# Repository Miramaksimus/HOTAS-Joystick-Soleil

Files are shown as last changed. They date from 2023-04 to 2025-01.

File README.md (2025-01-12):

# 3D-printed HOTAS Joystick Soleil: F-16 Sticks + housing + twist rudder controls

## Features:
- Removable stick
- Two different stick's size, improved stick's parts mounting, used other type of 5-way Hat/POV Switches
- Improved Gimbal parts mounting, corrected the dimensions of the holes for the bearings
- Two different types of housing, one with additional axes and toggles

## 3D Model
You can see the assembled 3D models in web:
- [Short Size Stick](https://a360.co/3PqR6vJ)

- [Normal Size Stick](https://a360.co/3PvqF8i)

- [Cylindrical JoyStick Base](https://a360.co/3Li3Hh7)

- [Rectangular JoyStick Base](https://a360.co/3q2hyS1)

## Printing
- White and black PLA+, red PET-G
- Rafts: Yes
- Supports: Yes
- Infill: 20 - 30 - 60%
 
## Components (not complete)
- Bearing 6802zz (15x24x5mm) - 5 units
- Bearing MF105zz - 8 units
- Bearing 685zz - 4 units
- Adhesive non-slip pad 200x200mm - 1 init
- The TLE5011/5010 sensors - 2 units
- Hall-effect sensor (SS49E for example) - 1 unit
- Ceramic capacitor 50V 104 100nF 0.1uf - 1 unit
- Cylindrical magnets (5x10mm) - 4 units
- 5-Way Switch 10x10x10mm Multi Direction Switch Touch Reset Button - 4 units
- Push Button 6x6 4.3mm - 5 units
- Miniature toggle switch (on/of/on or reset/of/reset ) - 2 units
- Potentiometer (WH148) 10K Ohm (B10K) - 3 units
- Switching Diode (for example 1N4148) - 30 units
- Micro-USB 5pin Micro USB 2.0 Male to USB 2.0 B Type Female Connector Cable 30cm With Panel Mount Hole cables - 1 unit
- Wires - 28-32 AWG 
- Hot Glue - 1 unit
- Two Component Epoxy Glue or Super Glue- 1 unit
- Low-cost STM32F103C8 microcontroller - 1 unit
- [FreeJoy soft and manual](https://github.com/FreeJoy-Team/FreeJoyWiki)

### Screws, nuts, etc…
- WiP - [See the answer to the issue](https://github.com/Miramaksimus/HOTAS-Joystick-Soleil/issues/3#issuecomment-2561463725)

##  Images
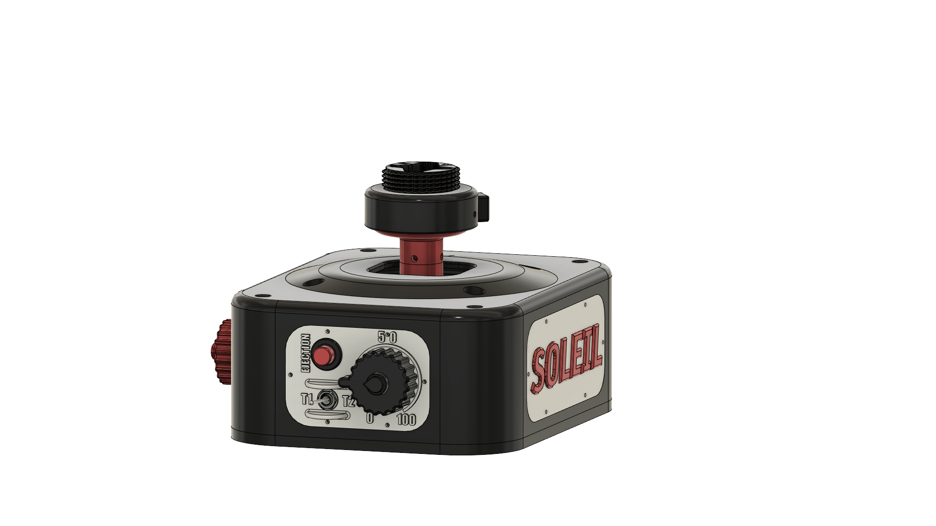
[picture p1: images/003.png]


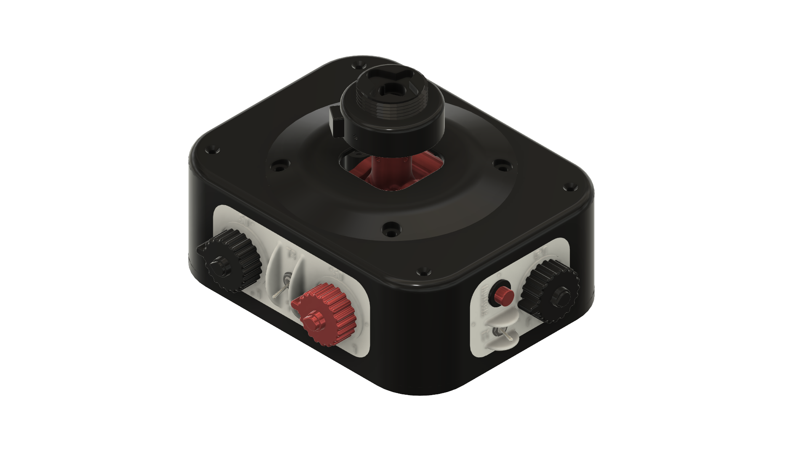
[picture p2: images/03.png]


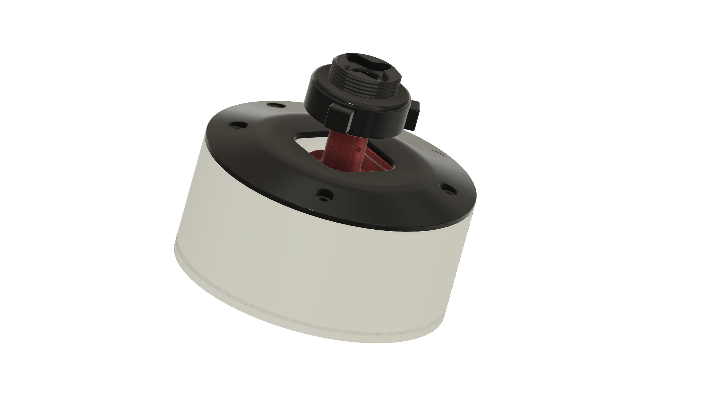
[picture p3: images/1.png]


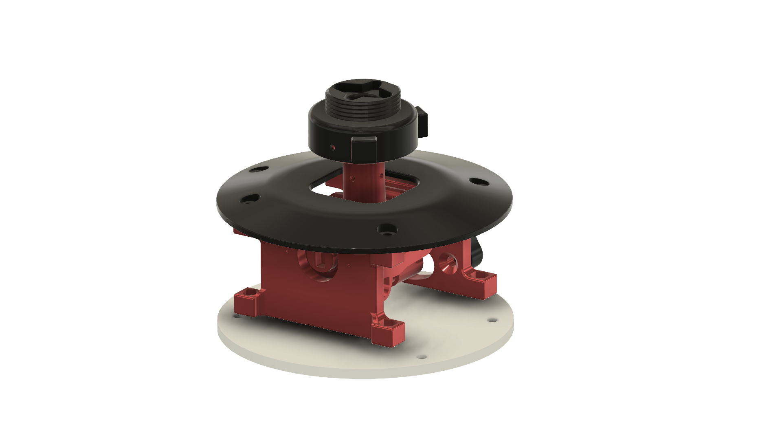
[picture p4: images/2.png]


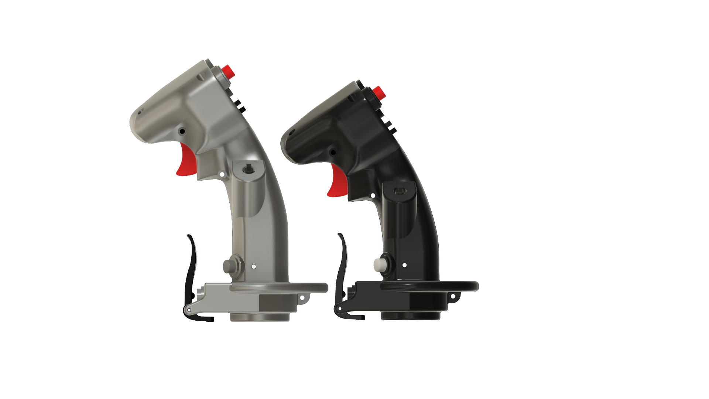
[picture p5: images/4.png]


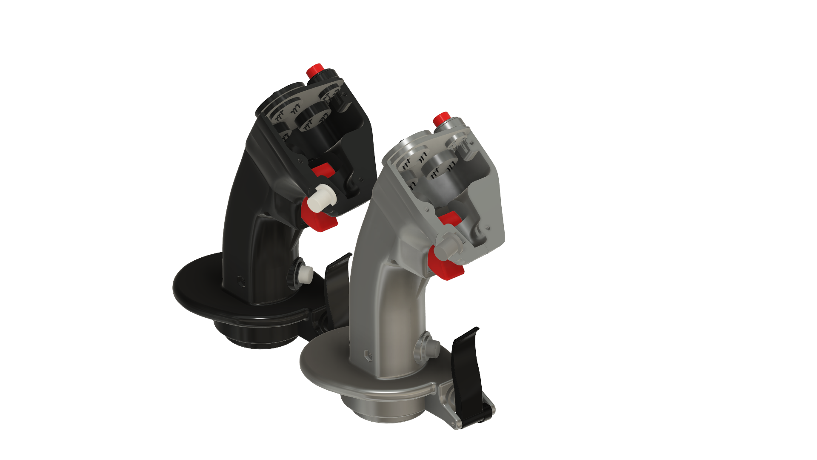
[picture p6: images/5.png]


##  Video

3D-printed HOTAS Joystick Soleil: F-16 Sticks + housings + twist rudder controls (https://www.youtube.com/watch?v=IS1_Lb0nVMM)

## **If you find this design helpful, consider  to support my work and my future projects. Thanks in advance.**

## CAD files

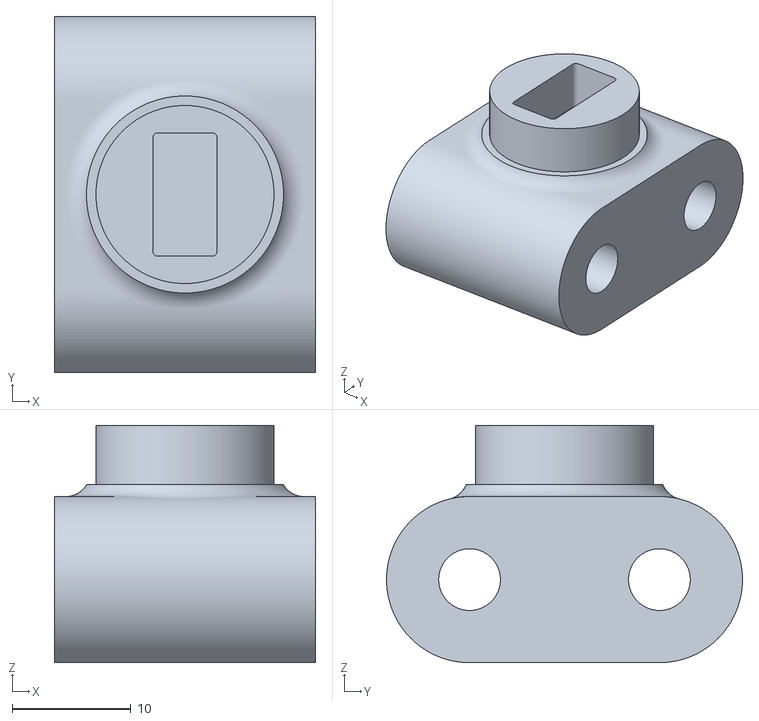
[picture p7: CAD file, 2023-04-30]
export/gimbal/stl/gimbal_core_pot_side.stl
22.0 x 30.0 x 20.0

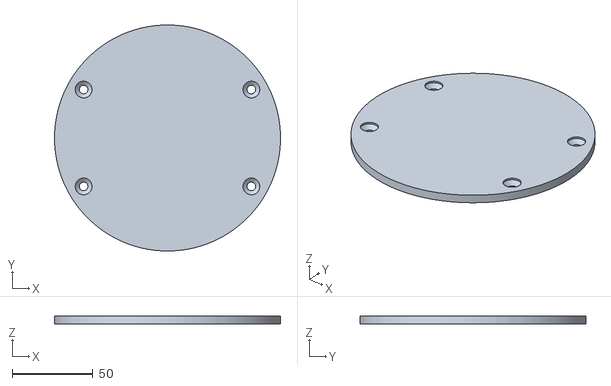
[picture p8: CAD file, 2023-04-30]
export/housing/cylindrical/stl/housing_base.stl
140.0 x 140.0 x 5.00

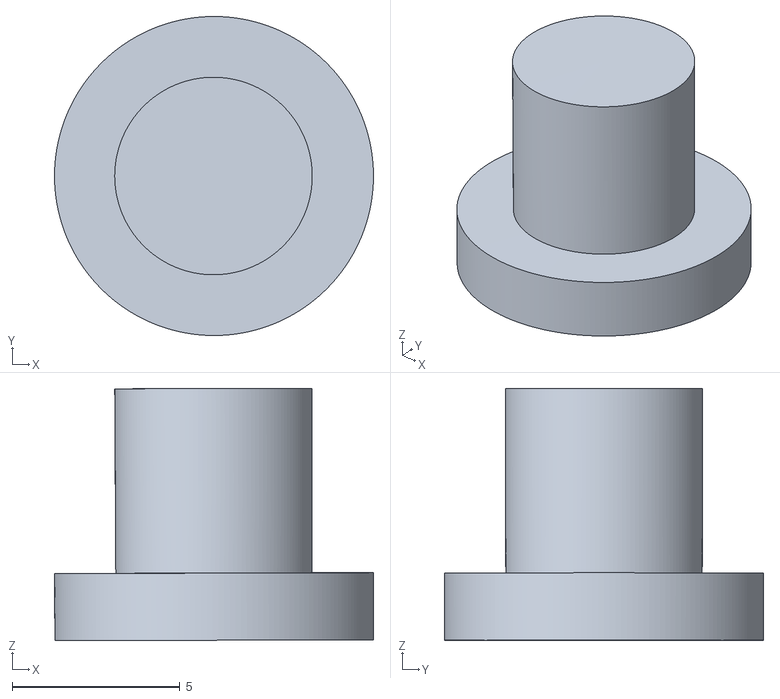
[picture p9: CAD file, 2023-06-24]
export/housing/rectangular/stl/button_rod.stl
9.51 x 9.51 x 7.53

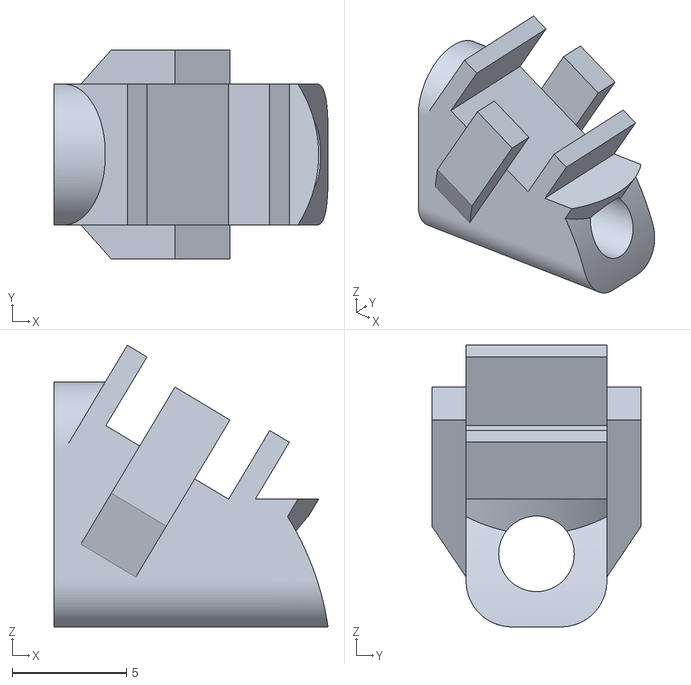
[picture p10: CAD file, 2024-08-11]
export/stick/common_parts/stl/pinkie_holder.stl
12.0 x 9.15 x 12.3

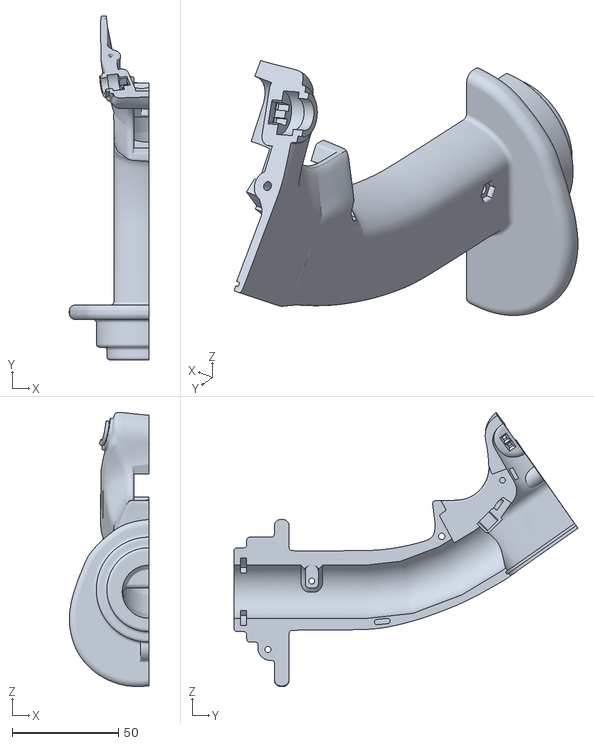
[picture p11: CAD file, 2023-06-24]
export/stick/normal/stl/Right.stl
37.4 x 162.0 x 129.1

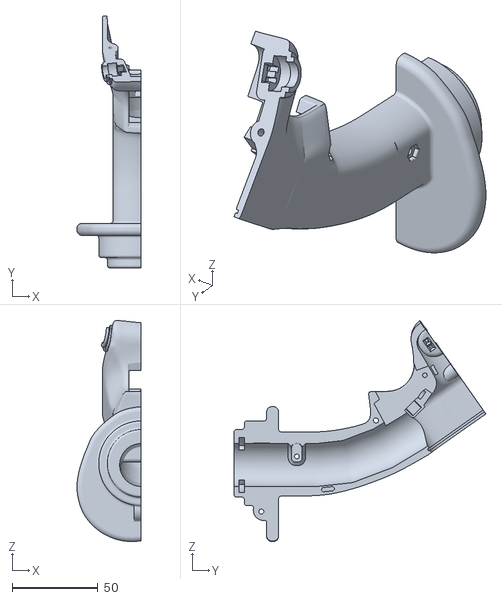
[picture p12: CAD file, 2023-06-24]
export/stick/short/stl/Short-right.stl
37.4 x 147.0 x 129.0

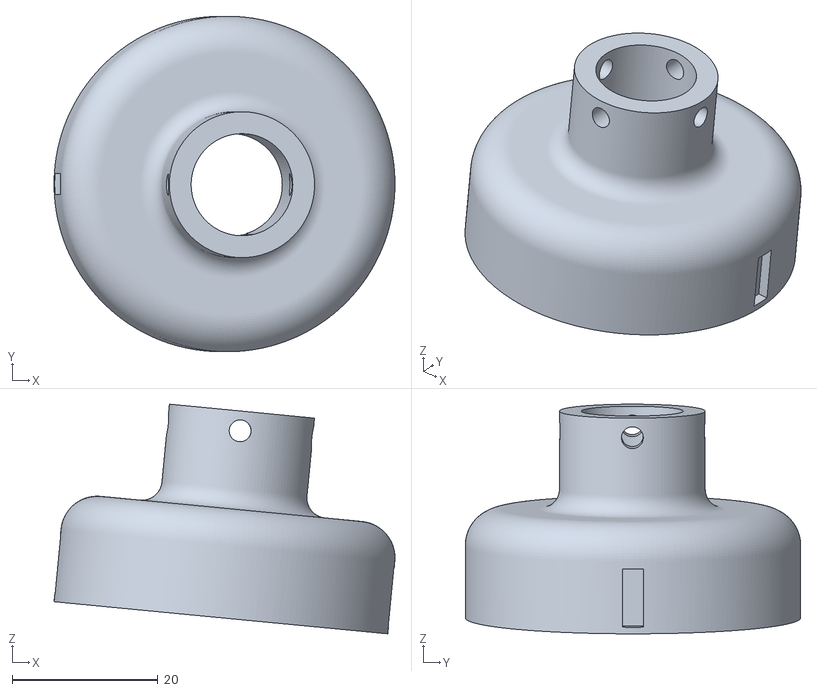
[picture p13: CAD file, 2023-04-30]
export/twist/stl/twist_rudder_controls_bottom_new.stl
46.8 x 46.0 x 31.5

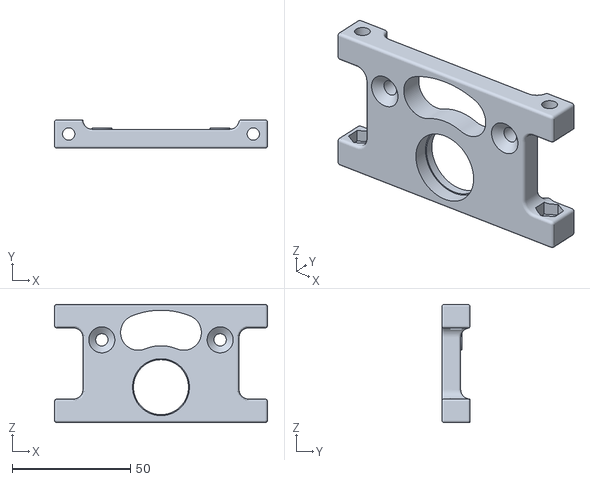
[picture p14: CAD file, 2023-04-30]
export/gimbal/stl/gimbal_frame_alt.stl
90.0 x 12.0 x 50.0

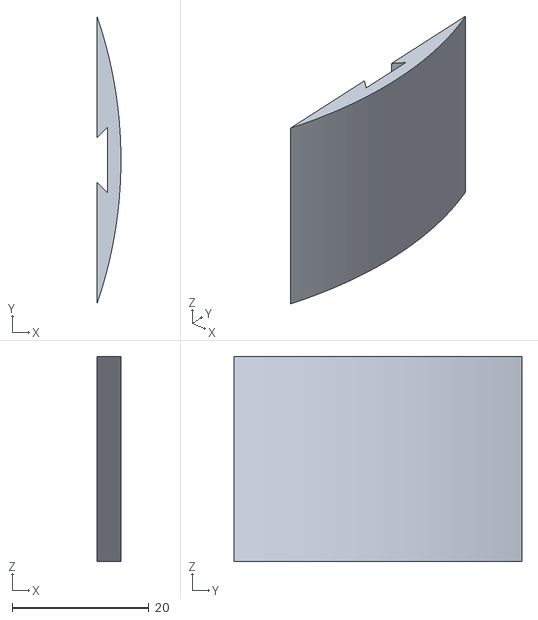
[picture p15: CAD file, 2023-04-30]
export/housing/cylindrical/stl/housing_bluepill_socket.stl
3.50 x 42.1 x 30.0

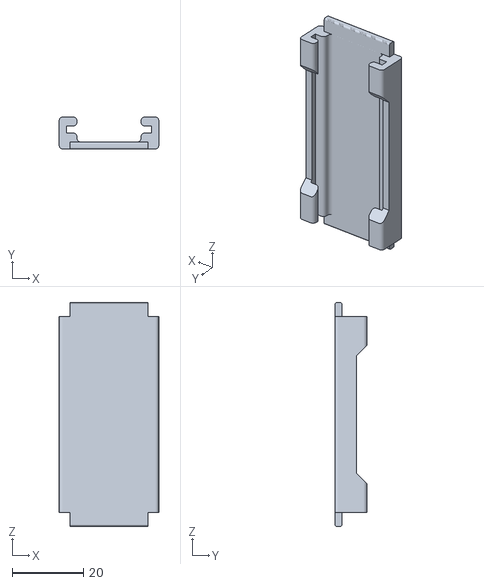
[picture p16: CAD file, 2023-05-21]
export/housing/rectangular/stl/bluepill-rect-frame.stl
28.0 x 9.00 x 63.0

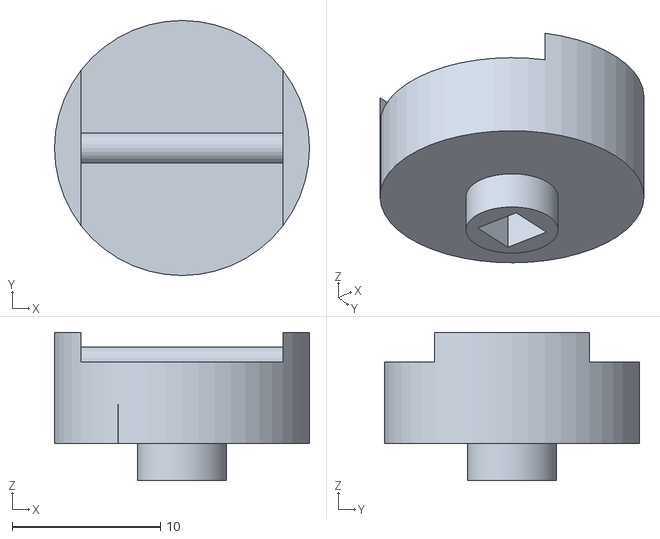
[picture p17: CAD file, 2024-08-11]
export/stick/common_parts/stl/cms_hat.stl
17.2 x 17.2 x 10.00

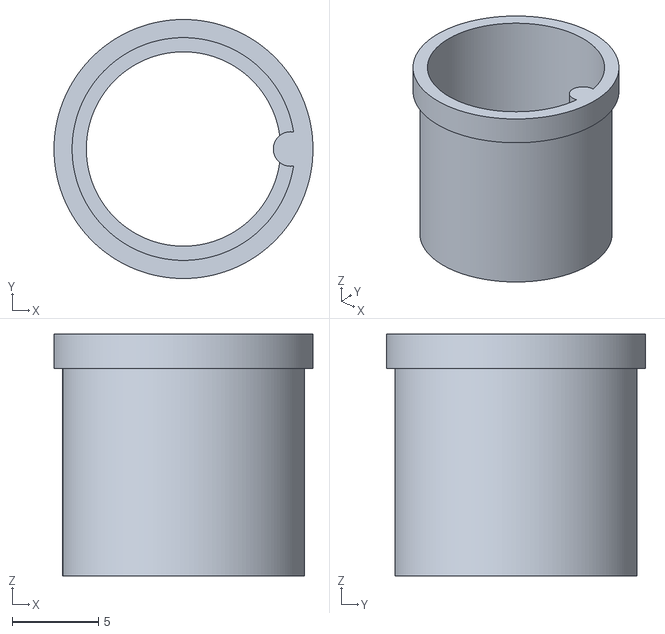
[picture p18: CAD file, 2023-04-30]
export/twist/stl/twist_adapder_top_bushing.stl
15.0 x 15.0 x 14.0

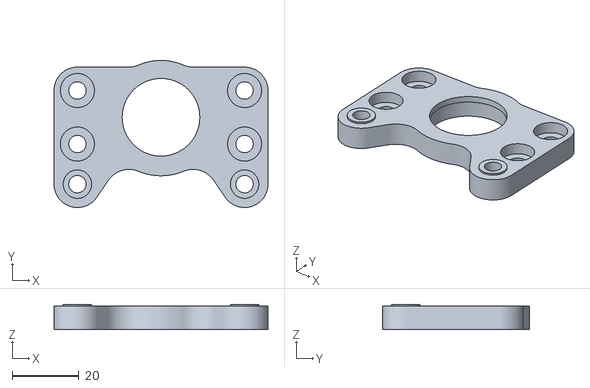
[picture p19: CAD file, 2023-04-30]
export/gimbal/stl/gimbal_core_bearing_carrier.stl
64.0 x 44.0 x 7.50

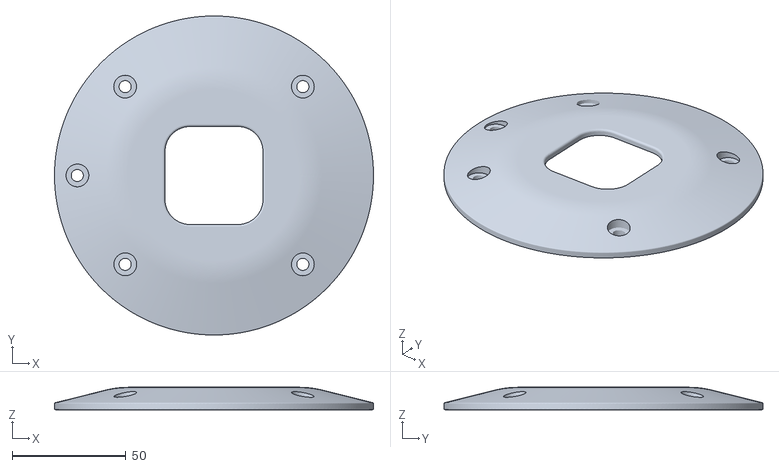
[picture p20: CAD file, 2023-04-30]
export/housing/cylindrical/stl/housing_cover.stl
140.0 x 140.0 x 9.88

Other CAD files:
export/housing/rectangular/stl/box_frame.stl
export/stick/common_parts/stl/dms_hat.stl
export/twist/stl/gimbal_lever_arm.stl
export/gimbal/stl/gimbal_core_bearing_carrier_alt.stl
export/gimbal/stl/gimbal_cam.stl
export/gimbal/stl/gimbal_core_non_pot_side.stl
export/gimbal/stl/gimbal_frame.stl
export/gimbal/stl/gimbal_lever_arm.stl
export/housing/cylindrical/stl/housing_bluepill-1.6mm.stl
export/housing/cylindrical/stl/housing_body.stl
export/housing/rectangular/stl/box_bottom.stl
export/housing/rectangular/stl/box_cover.stl
export/housing/rectangular/stl/button_red_cap.stl
export/housing/rectangular/stl/front_cover.stl
export/housing/rectangular/stl/left_cover.stl
export/housing/rectangular/stl/potentiometr_knob.stl
export/housing/rectangular/stl/right_cover.stl
export/housing/rectangular/stl/soleil.stl
export/stick/common_parts/stl/Face.stl
export/stick/common_parts/stl/Face_alter.stl
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

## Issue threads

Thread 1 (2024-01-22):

Questions about sensor and installation

LUCKandII, 2024-01-22:
Great job and thanks for your sharing!I have some question about the sensor and would you mind give me some answers?
* You mentioned 2 unit TLE5011/5010 sensors and 1 unit Hall-effect sensor in your project, I wonder which of these is for z axis?
* How to inatall z axis magnet?I don't see room to mount magnets and sensors. Can you share some pictures of the installation?
* TLE5011/5012 sensor use SPI bus for communication.Dose freejoy support 2 or more SPI device? In the configure page, it seems there's no distinction two different spi devices... Would you mind to share some key config (files/picture/anything else) about this?
* How do these two pieces fit together?If I use screws, it seems that it can't be twisted.

Thank you in advance for your help!

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

Miramaksimus, 2024-01-22:
Here are the fixed answers:

1. The TLE5011/5010 sensors are utilized for the X and Y axes, as demonstrated in the video (https://youtu.be/IS1_Lb0nVMM?t=363). For the Z-axis, a Hall-effect sensor is employed (image1) -use hot glue to secure the sensor position.
2. For guidance on installing the Z-axis magnets, refer to the available images demonstrating the installation process (image2 and image3).
3. For configuring the TLE5011/5010 sensors (not the TLE5012), please find my configuration details in image4.
4. If you wish to disable the twisting functionality, screws are provided for this purpose. However, if you want to enable twisting, it is recommended to use super glue for assembly. Secure the twist's bottom part with super glue to the bearing, assemble the twist, check for proper functionality, and then attach the top twist part with super glue to the inside of the bearing. This method ensures a secure assembly while allowing the necessary twisting motion. (See how to install the bearing: https://youtu.be/IS1_Lb0nVMM?t=381)

For more in-depth information and insights from the community, it is advised to check the description, comments, and responses on the Thingiverse page (https://www.thingiverse.com/thing:5976575). Exploring remixed versions and related content on Thingiverse can also provide valuable tips, modifications, and community feedback.

Additionally, you can find helpful visual guides and demonstrations related to joysticks on my YouTube channel (https://www.youtube.com/watch?v=4qccZbGVc9M&list=PL6WOn1wgybe4zLbwNDsI1c768gBqbFAPy&index=4).

image1

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

image2
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

image3
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

image4
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

LUCKandII, 2024-01-27:
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

Thank you! I've prepared all 3d printed components and "shopping list".  I think the best way to thank you is to recreate your work!

Closed 2024-01-23.

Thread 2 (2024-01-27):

Question about wiring hardware connection

LUCKandII, 2024-01-27:
Hi, I've watched your youtube video and your thingiverse page and really learned a lot! I also have some questions about wiring hardware connection:

* How to connect 4/5-way Switch to stm32 blue pill? Do you use 4/5-way Switch as keyboard array? Would you mind to share some more information about this?

* It makes me more curious about your wiring that you flight stick is replaceably with pogopin! It seems impossible to connect all the switch on the stick with only 10 pogopins (showed in the video) since it has FOUR 4/5-way switch and TWO push buttons because 4/5-way switch has at least 4 pin for each and push has at least 1 pin for each.Do you used resistance to make 4/5-way switcs as analog output? Would you mind to share more information about you pogopin design?

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

Miramaksimus, 2024-01-27:
Hi, there is one answer to your two questions - a matrix of buttons. You can find more details [here](https://github.com/FreeJoy-Team/FreeJoyWiki/blob/master/eng/Connecting-buttons-directly-to-controller.md).

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

With a 5x5 matrix, you can connect 25 buttons on the F-16 stick:

- three 5-way switches
- one 4-way switch
- 6 buttons

In the screenshot with the pin configuration from your previous issue, you can see a 5x6 matrix configured, which allows connecting 30 buttons (25 on the stick and 5 on the base of SOLEIL).

[The WiKi of the FreeJoy project](https://github.com/FreeJoy-Team/FreeJoyWiki/tree/master) could be useful for you.

LUCKandII, 2024-02-29:
Thanks for your help! I couldn't wait to share my joystick to you!
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

Miramaksimus, 2024-03-02:
You are welcome! It is amazing make! If you wont you can post your make in https://www.thingiverse.com/thing:5976575

I uploaded short video that can help you with trigger:

https://www.youtube.com/shorts/-YpK8iMiVb8

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

LUCKandII, 2024-03-10:
Thanks a lot! I fixed my trigger finally and made a [throttle-quadrant](https://github.com/Miramaksimus/throttle-quadrant-fokker-8-axes-and-31-buttons) these day! So excited to share with you!
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
I have a new question now... I connected stick and throttle to PC and running DCS, but one of my freejoy device setting is invalid. Did you use both stick and throttle in the same time and meet similar problem? I guess it might have something to do with the freejoy USB VID and PID https://github.com/FreeJoy-Team/FreeJoy/issues/209#issuecomment-1975108704.  I tried to modify USB VID and PID but this problem still unsolved. Do you have any ideas?

LUCKandII, 2024-03-10:
Well... Modifying USB VID and PID does work! All needed to do is restart DCS program!
I will post my making to thingivese later!

LUCKandII, 2024-03-23:
@Miramaksimus
Here is my make!
https://www.thingiverse.com/make:1165394
https://www.thingiverse.com/make:1165395

Miramaksimus, 2024-03-23:
Thank you!

Ahmet0691, 2024-11-12:
Can you share a photo of the direction of the diode facing the key? What is the name of the connectors you are using? And what is the task of bringing the joystick back to the center point, is it a spring or a rubber? [Is the diode looking at the chip or the button?]

LUCKandII, 2024-11-13:
> Can you share a photo of the direction of the diode facing the key? What is the name of the connectors you are using? And what is the task of bringing the joystick back to the center point, is it a spring or a rubber? [Is the diode looking at the chip or the button?]

* A photo of the direction of the diode facing the key. I made a key matrix PCB and all diodes are weilding on it. The diode is IN4148W, SOD-123 footprint.
* Any wire-to-wire connector is fine as long as it's easy to buy. I don't have an exact name of my connector... It's just some kind of 1.25mm 6P wire-to-wire connector.
* Joystick back to the center point using spring. [This video gives more information](https://www.youtube.com/watch?v=IS1_Lb0nVMM)
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

SirPotatoCat, 2024-12-21:
> Thanks for your help! I couldn't wait to share my joystick to you! It works perfect except the trigger botton.I will try to fix it. Your throttle quadrant is my next goal! ![1000012699](https://private-user-images.githubusercontent.com/44010936/308768615-df7ef069-b023-4bdc-b04c-dadd48d03fa9.jpg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) ![1000012700](https://private-user-images.githubusercontent.com/44010936/308768640-fe9db7c2-2d38-43e6-8a9b-feb0b18bd15a.jpg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) ![1000012701](https://private-user-images.githubusercontent.com/44010936/308768654-421a5d77-4dad-45a6-8af6-45d2ac85e38a.jpg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) ![1000012705](https://private-user-images.githubusercontent.com/44010936/308768666-02b718bc-bc69-4e15-8511-56ec3dc625d0.jpg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)

I'm looking forward to building this, I have all the parts ready to order but i was wondering if you knew which screws is should order? The originally model he remixed this from seemed to just screw right into the plastic but in his video he has nuts?

LUCKandII, 2024-12-22:
> I'm looking forward to building this, I have all the parts ready to order but i was wondering if you knew which screws is should order? The originally model he remixed this from seemed to just screw right into the plastic but in his video he has nuts?

Nuts are necessary. Mostly M3 and M4 nuts. It's a compoment list in readme of this project.

Miramaksimus, 2024-12-22:
> Can you share some information about joystick pogopin definition? Is it the same as warthgo HOTAS?

Yes, it is remixed from https://www.thingiverse.com/thing:3097965

Closed 2024-01-31.

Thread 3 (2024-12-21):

Screws

SirPotatoCat, 2024-12-21:
I'm looking forward to building this, I have all the parts ready to order but i was wondering if you knew which screws is should order? The originally model he remixed this from on thingverse seemed to just screw right into the plastic but in his video he has nuts?

Sciencesold, 2024-12-24:
Primarily its M5 hardware with a few M3 and M2, I have a variety pack of both with the M5 having various lengths between 8mm and 35mm. you do nee 2 Flat Head m5, but everything else can be Button Head. All the nuts are M5 obviously. You only need a handful of M3, primarily for the main top and bottom plates and the stick. I don't know the lengths off the top of my head, but one was a longer size I had to order a pack with m3x25 through m3x40 to find one that worked. M2 are for attaching the side plates.

Wizard-pope, 2025-01-11:
> Primarily its M5 hardware with a few M3 and M2, I have a variety pack of both with the M5 having various lengths between 8mm and 35mm. you do nee 2 Flat Head m5, but everything else can be Button Head. All the nuts are M5 obviously. You only need a handful of M3, primarily for the main top and bottom plates and the stick. I don't know the lengths off the top of my head, but one was a longer size I had to order a pack with m3x25 through m3x40 to find one that worked. M2 are for attaching the side plates.

Would you be able to take the time to documetn the actual needed lengths? Or should I just order a variety pack of M5 M3 and M2?

Closed 2025-01-11.

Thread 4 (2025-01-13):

Wiring Schematic/Custom PCB?

Valshade, 2025-01-13:
Hello, First of all i'd like to thank you for a great project everything looks well laid out and the end product looks like it will be extremely accurate. I looked up the listed electronic components and by the images in your video it looks like the hall sensors are mounted to some sort of custom PCB. Do you have the gerber file or some other format for the PCB? Thanks Again!

Wizard-pope, 2025-01-13:
If you are talking about the TLE5010 you can buy them with the PCB [https://vi.aliexpress.com/item/1005006477243651.html?gatewayAdapt=glo2vnm](like such).

Valshade, 2025-01-13:
Gotcha, makes more sense now!

sigmastk, 2025-02-14:
Hey @Valshade you can make them even cheaper (if you have time and soldering skills).

This is schematic for the TLE5010 board:

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

Wizard-pope, 2025-02-14:
You could yes but if you don't have all the resistors and capacitors already it might end up costing the same just to get the components. If you have everyrhing apart from the chip itself it makes sense.

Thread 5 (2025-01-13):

Screw sizes and such

Wizard-pope, 2025-01-13:
I went through all the files and assembled a list of what I believe to be all the necessary bolts and nuts for this project. I have not yet printed all the parts so cannot confirm if this is 100% accurate but I think I got most of it. If anyone with an assembled project can verify I would be very happy.

[SOLEIL screws.txt](https://github.com/user-attachments/files/18397787/SOLEIL.screws.txt)

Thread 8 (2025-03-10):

Tutorial Video

EmircanLalecan, 2025-03-10:
Hi, thanks for making great project. I am a newbie to flight sim and I really want to make a reliable HOTAS for myself to jump into flight sim hobby. I came across to this github page and i loved the design and functionality of it. But my lack of knowledge and inexperience made it impossible for me to do anything. Also I couldn’t find any complete parts list anywhere on the internet. Is it possible for you or anyone else to make a detailed tutorial video where video creator shows whole parts lists, wiring, assembly and set up processes individually?

Laroto, 2025-05-01:
Same issue here. I cannot figure out how the yaw axis work. I could not find a spring in the BOM.
@Miramaksimus

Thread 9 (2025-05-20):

Can you help me with the wiring and matrix?

SaidBYzzz, 2025-05-20:
**Hi MagniBY,**

First of all, thank you very much for your amazing project. I really appreciate your work on the throttle and joystick project I’ve learned a lot from it!

I must admit that I’m a beginner when it comes to electronics. I've completed the enclosure and prepared the STM32F1 board. FreeJoy is working, and I've tested some basic button inputs on a breadboard successfully. However, I’ve been struggling with getting the button matrix to work for the past three days.

During this time, I tried to understand how button matrices work by reading the FreeJoy Wiki, checking ChatGPT, watching YouTube videos, and searching online, but I still couldn’t get a working setup. I need a 5x6 matrix (5 rows, 6 columns) to handle 30 functions, including the gimbal hat switches.

### Here are the parts I don’t fully understand:

Tactile switches have 4 pins, but I read that only 2 are needed one connected to a row and one to a column
and I also need to add a diode to prevent ghosting.

But for hat switches, they only have 5 direction pins + 1 GND, not 2 pins per direction like tact switches.

For ON/OFF/ON switches, I see 2 direction pins + 1 GND.

So do hat/ON/OFF/ON switches need two connections per direction (one to a row, one to a column) like in the matrix, or just one connection?

Should I connect the GND pins of the Hat/ON-OFF-ON switches to the STM32F1 board, or is that unnecessary since I’m using a button matrix?

I also learned that I could use a shift register to simplify things, but I found that out after I had already started working on the matrix. I can’t order more components now due to shipping costs I’ve already bought parts from four different sites. As far as I know, you're also using a matrix in your project.

I tried to build a simple 2x2 matrix on a breadboard for testing, but only button 1 and 4 work in FreeJoy. Buttons 2 and 3 do nothing.

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

So as you can probably tell, I'm really bad at electronics

### I have a second question (which might be better suited for the FreeJoy GitHub 😅):

I chose the AS5600 sensors for the X and Y axes because they’re much more affordable compared to TLE5010/11  almost 10 times cheaper and thanks to this remix (https://www.thingiverse.com/thing:5874121), I was able to mount them onto the Olukelo gimbal. I think 12-bit resolution is good enough for my purposes.

However, FreeJoy only allows a single I2C port (B10/B11). But since I have two AS5600 sensors, don’t I need two separate I2C?
Why doesn’t FreeJoy allow using other pins for I2C?

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

Thanks again for everything you’ve created and shared. If you have any suggestions or corrections, I’d be extremely grateful!

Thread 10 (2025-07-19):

i used the esp32 s3 nano insted of the blue pil

kalmanido9, 2025-07-19:
i used the gamge controller for calibrations its biult into windows idk its much easier for me to create my own insted of using the blue pil wich has little to no costomazetions in terms of power and addons like screens or such that i will add later not only the joyistick itself
#include <USB.h>
#include <USBHIDGamepad.h>

USBHIDGamepad Gamepad;

#define X_PIN A5  // GPIO1
#define Y_PIN A3  // GPIO3

const int ROWS = 5;
const int COLS = 5;
const uint8_t rowPins[ROWS] = {8, 9, 10, 11, 12};
const uint8_t colPins[COLS] = {2, 3, 4, 5, 6};

void setup() {
  USB.begin();
  Gamepad.begin();

  for (int r = 0; r < ROWS; r++) {
    pinMode(rowPins[r], OUTPUT);
    digitalWrite(rowPins[r], HIGH);
  }
  for (int c = 0; c < COLS; c++) {
    pinMode(colPins[c], INPUT_PULLUP);
  }

  pinMode(X_PIN, INPUT);
  pinMode(Y_PIN, INPUT);
}

void loop() {
  static uint32_t lastSend = 0;

  if (millis() - lastSend > 5) {
    int rawX = analogRead(X_PIN);  // 0–4095
    int rawY = analogRead(Y_PIN);

    int joyX = map(rawX, 0, 4095, -127, 127);
    int joyY = map(rawY, 0, 4095, -127, 127);

    joyX = constrain(joyX, -127, 127);
    joyY = constrain(joyY, -127, 127);

    uint32_t buttons = readMatrixButtons();

    Gamepad.send(joyX, joyY, 0, 0, 0, 0, 0, buttons);

    lastSend = millis();
  }
}

uint32_t readMatrixButtons() {
  uint32_t state = 0;
  for (int r = 0; r < ROWS; r++) {
    digitalWrite(rowPins[r], LOW);
    delayMicroseconds(5);
    for (int c = 0; c < COLS; c++) {
      int index = r * COLS + c;
      if (!digitalRead(colPins[c])) {
        state |= (1UL << index);
      }
    }
    digitalWrite(rowPins[r], HIGH);
  }
  return state;
}
arduino ide was used and potentiometers insted of the regular tle i had some issues using them so i switched to simpler pot on the x/y with some 3d printed addapter wich i glued unto the chassy also with the esp32 i can connect multiple things like additional throttle and buttons and radar screen wich all connect via esp now and there for only one cable goes to the pc and everything works together

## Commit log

2023-04-30 add part
    [twist_rudder_controls_bottom_new.stl]
2023-05-21 added Soliel housing
    [botton_red_cap.stl, box_bottom.stl, box_cover.stl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]
2023-05-21 added adapted bluepill frame
    [bluepill-rect-frame.stl]
2023-06-24 Added last stl files
    [Face.stl, Face_alter.stl, Right.stl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]
2024-08-11 added "missing" stl's from remixed things
    [button_ctrl.stl, button_side.stl, cms_hat.stl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]
